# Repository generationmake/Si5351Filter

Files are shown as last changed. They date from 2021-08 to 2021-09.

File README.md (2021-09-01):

# Si5351Filter
Filter board for Si 5351 for WSPR or similar purposes.

Should fit perfectly to the [Adafruit Si5351A Clock Generator Breakout Board](https://www.adafruit.com/product/2045)

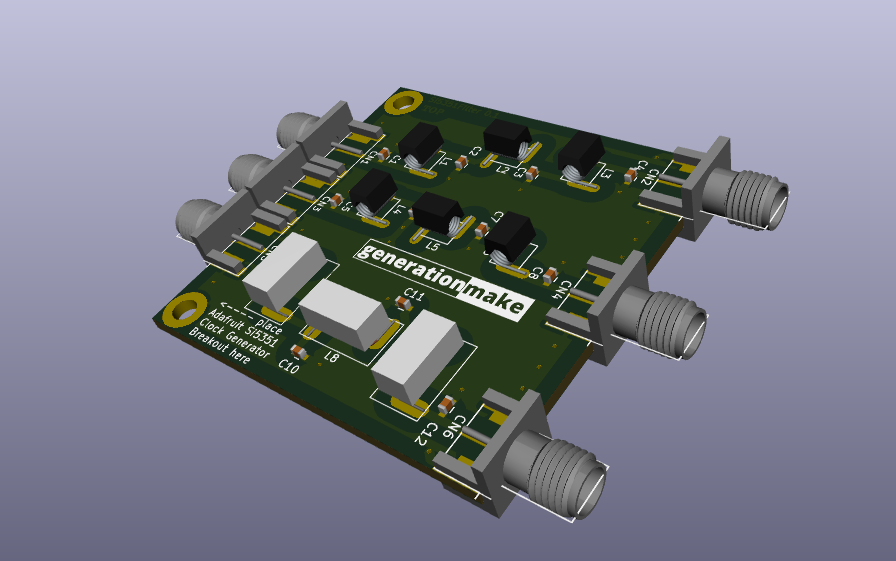
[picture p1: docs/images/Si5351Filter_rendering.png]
Si5351Filter rendering


## PCB

### Top

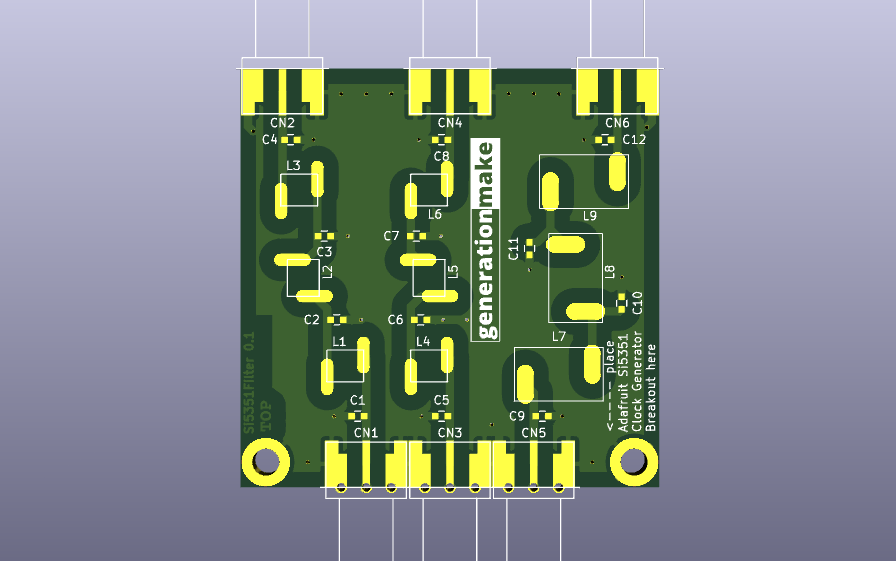
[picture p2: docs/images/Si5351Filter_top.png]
Si5351Filter PCB top


### Bottom

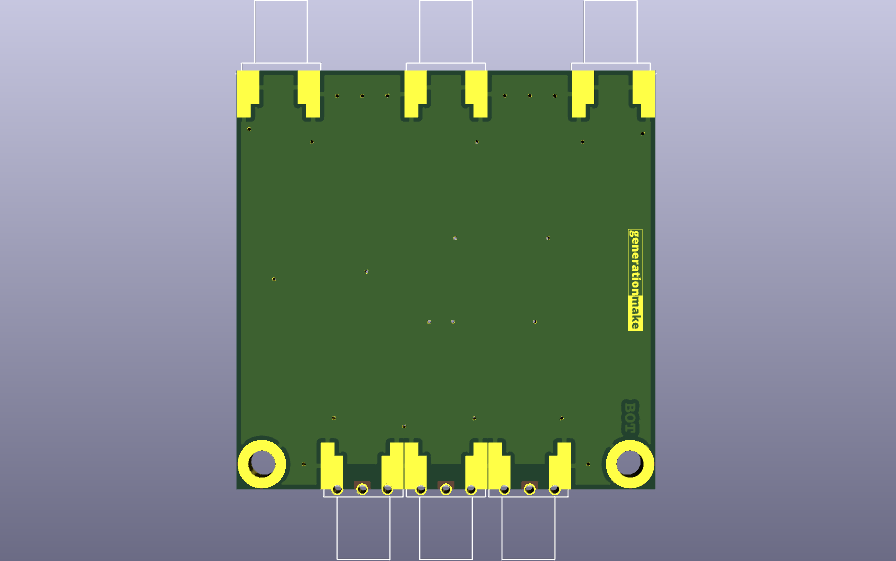
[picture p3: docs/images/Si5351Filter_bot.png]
Si5351Filter PCB bot


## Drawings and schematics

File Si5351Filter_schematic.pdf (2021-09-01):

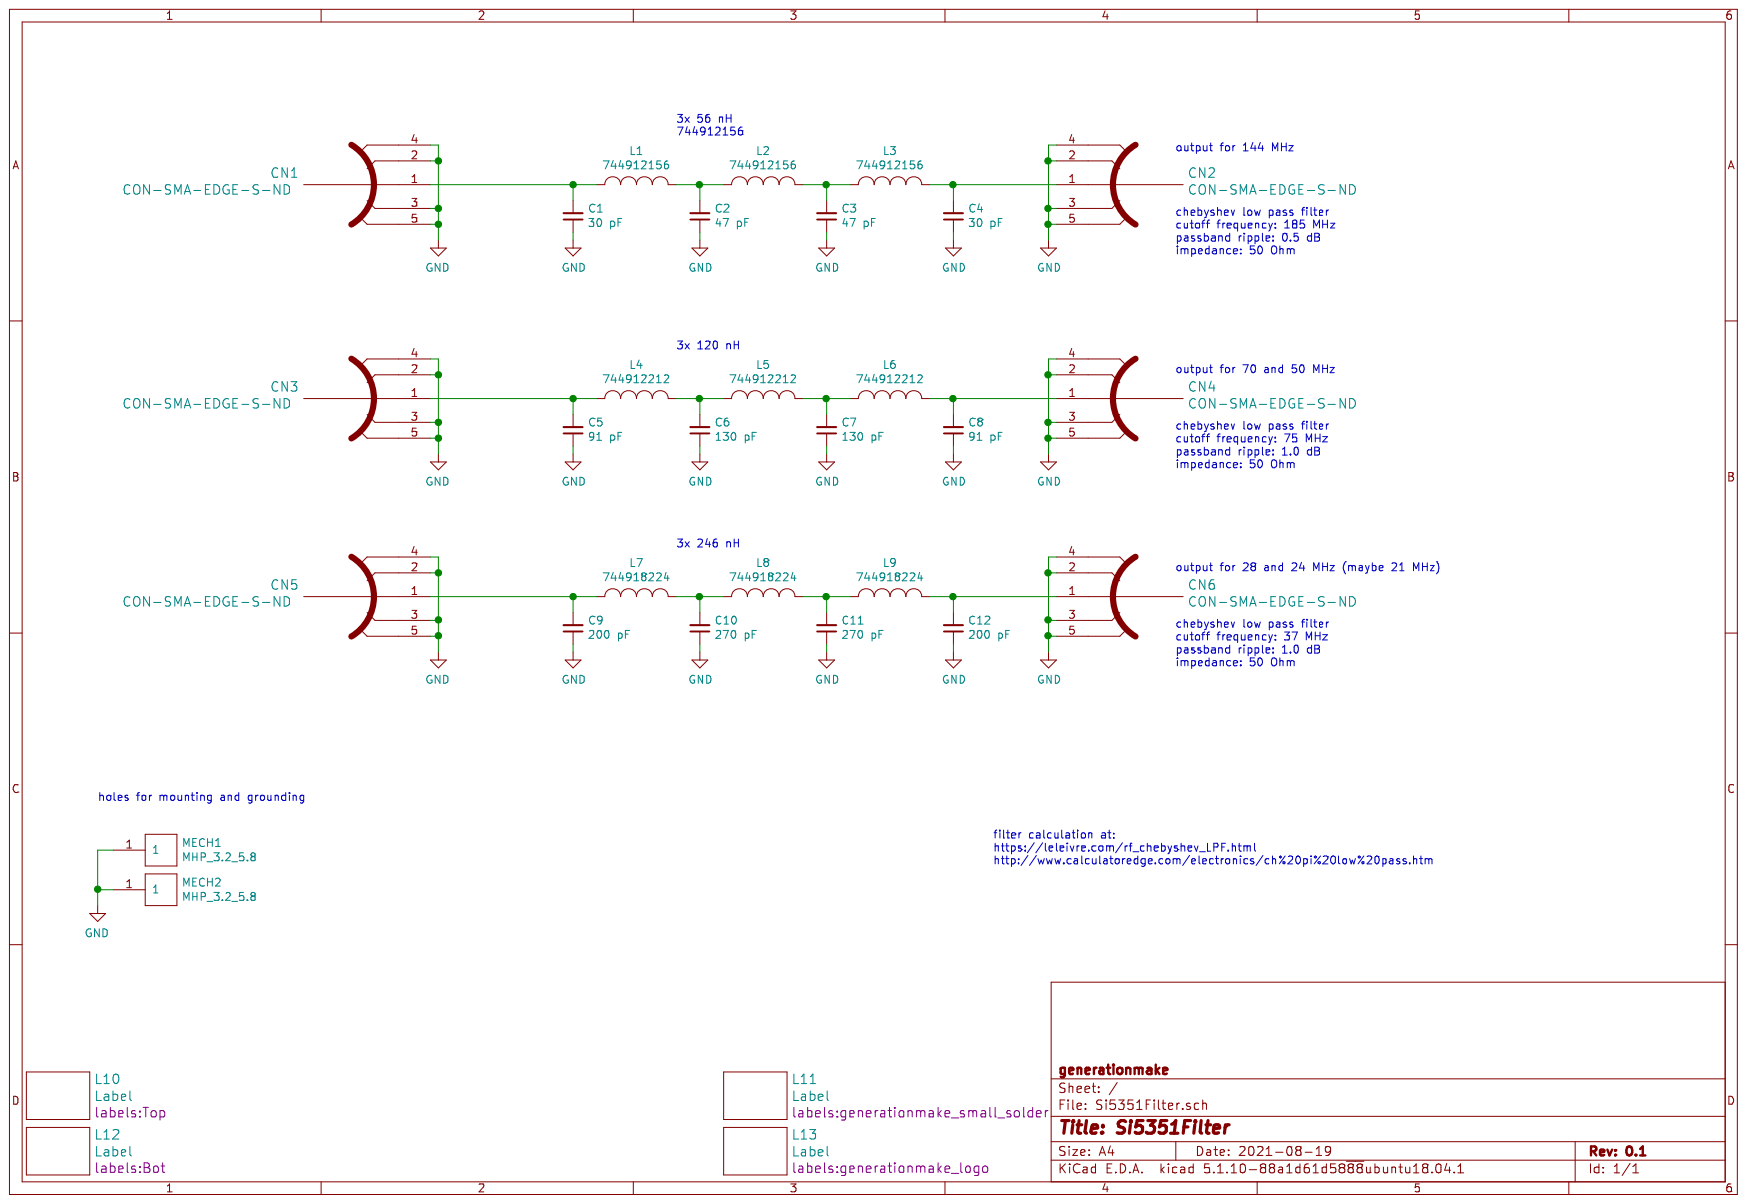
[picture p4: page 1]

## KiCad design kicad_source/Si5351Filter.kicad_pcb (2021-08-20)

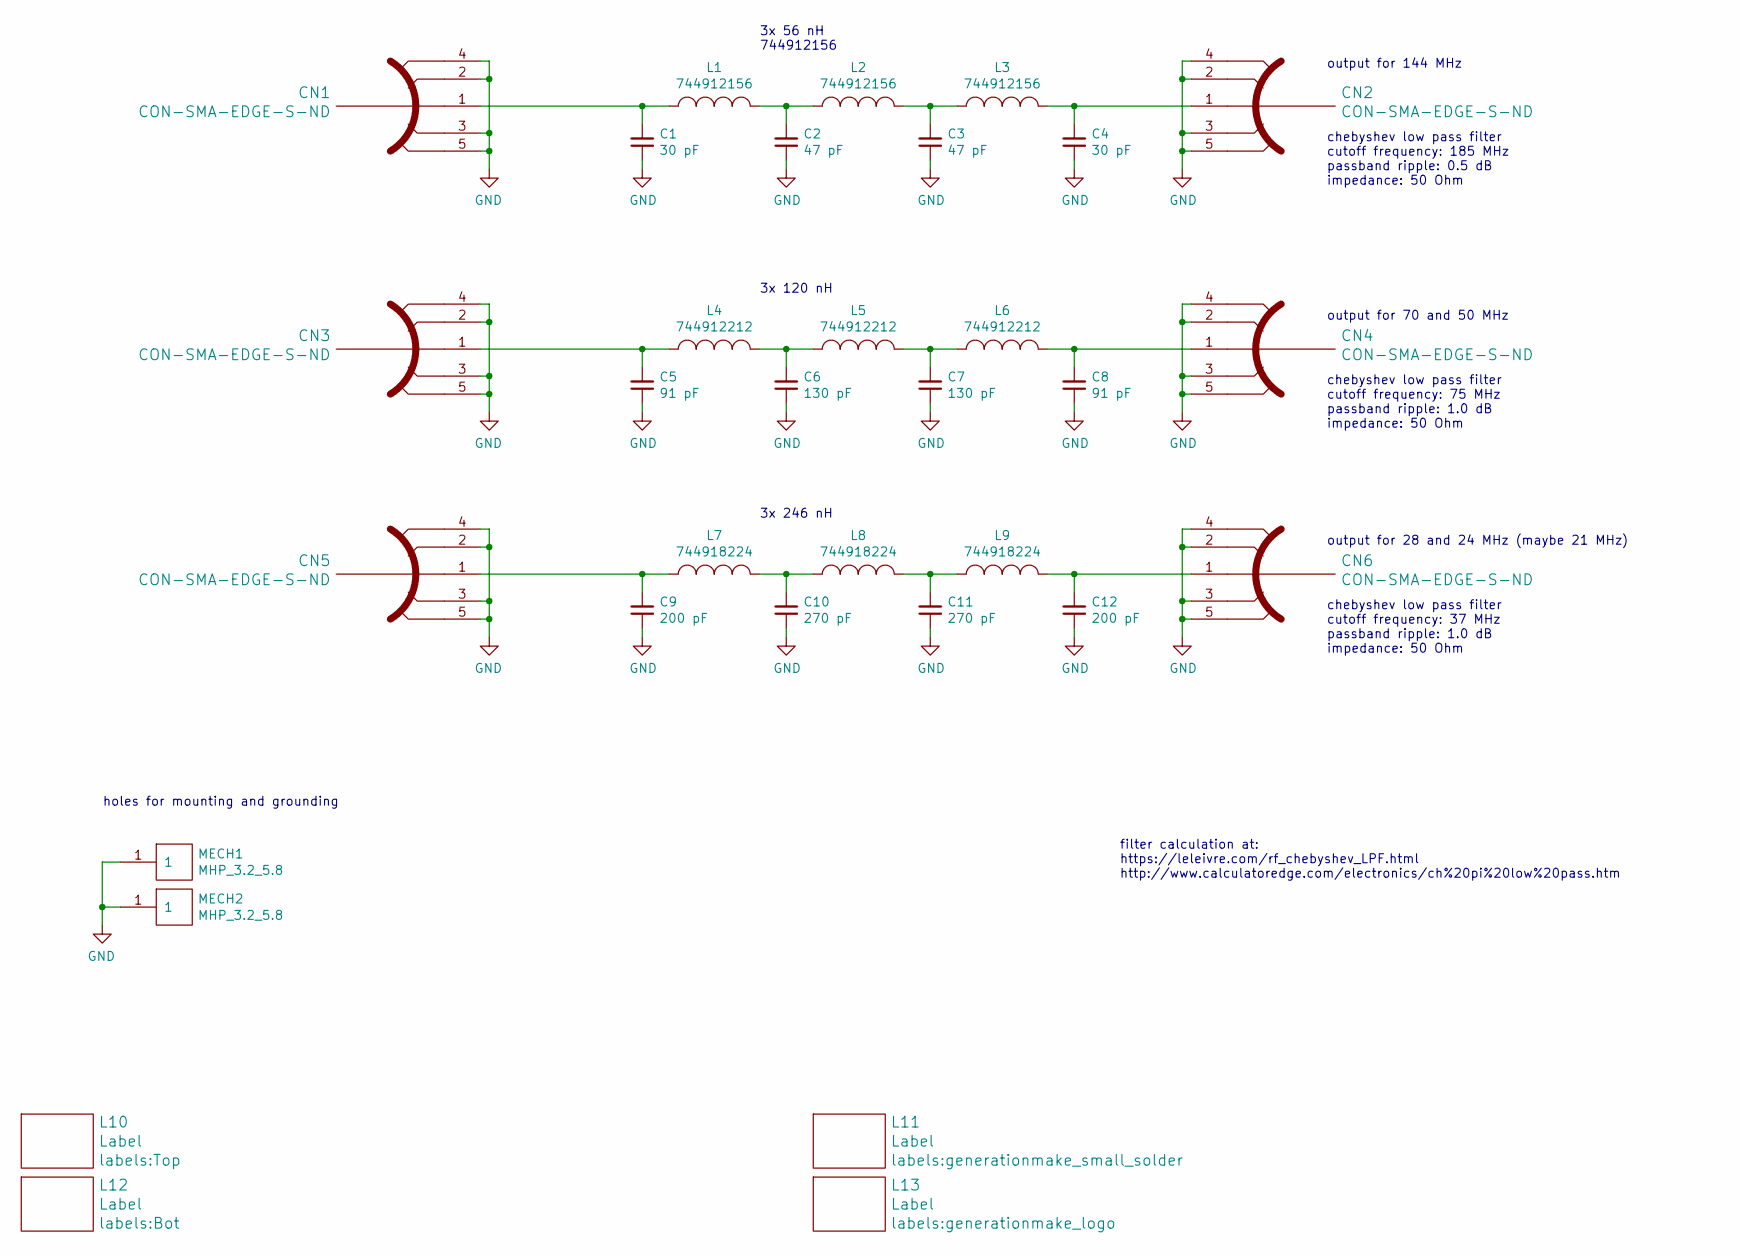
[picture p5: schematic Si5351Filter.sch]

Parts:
C1, C4: 30 pF; C_0603
C2, C3: 47 pF; C_0603
C5, C8: 91 pF; C_0603
C6, C7: 130 pF; C_0603
C9, C12: 200 pF; C_0603
C10, C11: 270 pF; C_0603
CN1, CN2, CN3, CN4, CN5, CN6: CON-SMA-EDGE-S-ND; WR-SMA-PCB_dual
L1, L2, L3: 744912156; WE-CAIR_4248
L4, L5, L6: 744912212; WE-CAIR_4248
L7, L8, L9: 744918224; WE-CAIR_5910
L10: Label; Top
L11: Label; generationmake_small_solder
L12: Label; Bot
L13: Label; generationmake_logo
MECH1, MECH2: MHP_3.2_5.8

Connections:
GND: C1.1, C2.1, C3.1, C4.1, C5.1, C6.1, C7.1, C8.1, C9.1, C10.1, C11.1, C12.1, CN1.2, CN1.3, CN1.4, CN1.5, CN2.2, CN2.3, CN2.4, CN2.5, CN3.2, CN3.3, CN3.4, CN3.5, CN4.2, CN4.3, CN4.4, CN4.5, CN5.2, CN5.3, CN5.4, CN5.5, CN6.2, CN6.3, CN6.4, CN6.5, MECH1.1, MECH2.1
unnamed: C1.2, CN1.1, L1.1
unnamed: C2.2, L1.2, L2.1
unnamed: C3.2, L2.2, L3.1
unnamed: C4.2, CN2.1, L3.2
unnamed: C5.2, CN3.1, L4.1
unnamed: C6.2, L4.2, L5.1
unnamed: C7.2, L5.2, L6.1
unnamed: C8.2, CN4.1, L6.2
unnamed: C9.2, CN5.1, L7.1
unnamed: C10.2, L7.2, L8.1
unnamed: C11.2, L8.2, L9.1
unnamed: C12.2, CN6.1, L9.2

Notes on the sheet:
output for 144 MHz
output for 70 and 50 MHz
3x 120 nH
3x 56 nH 744912156
chebyshev low pass filter cutoff frequency: 185 MHz passband ripple: 0.5 dB impedance: 50 Ohm
chebyshev low pass filter cutoff frequency: 75 MHz passband ripple: 1.0 dB impedance: 50 Ohm
filter calculation at: https://leleivre.com/rf_chebyshev_LPF.html http://www.calculatoredge.com/electronics/ch%20pi%20low%20pass.htm
output for 28 and 24 MHz (maybe 21 MHz)
3x 246 nH
chebyshev low pass filter cutoff frequency: 37 MHz passband ripple: 1.0 dB impedance: 50 Ohm
holes for mounting and grounding

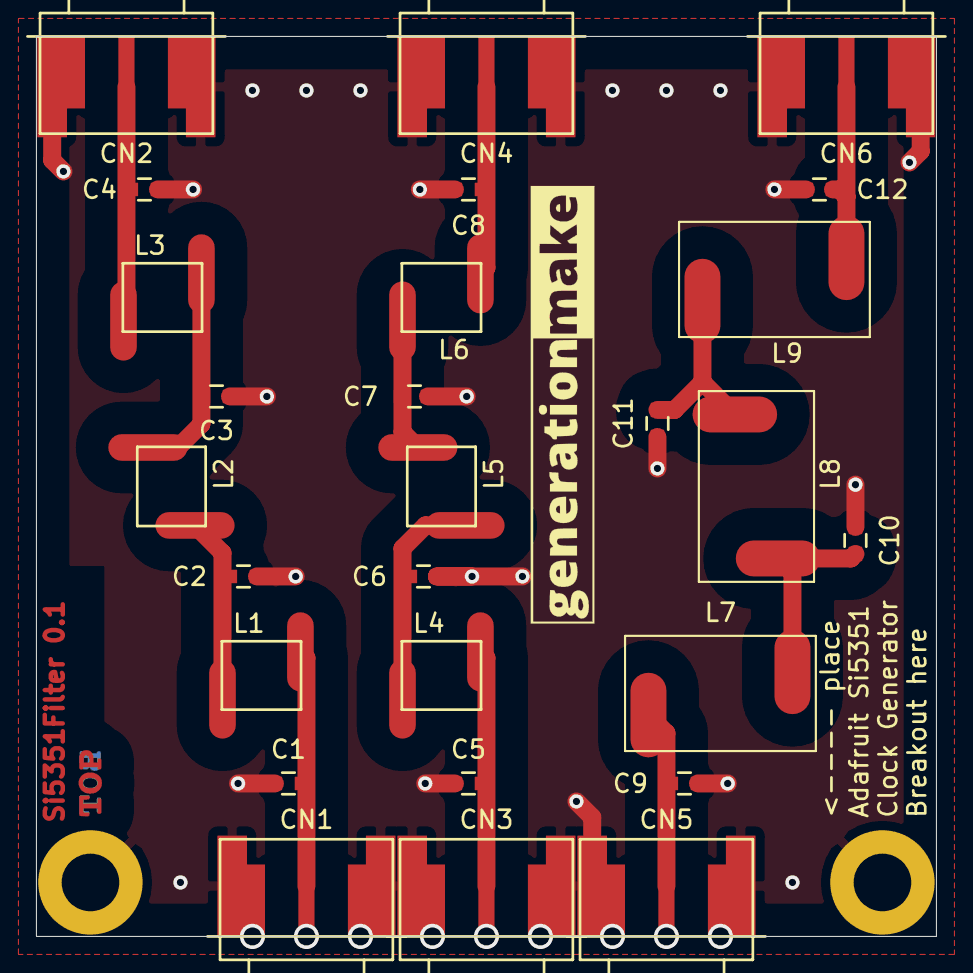
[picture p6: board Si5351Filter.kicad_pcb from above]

Board: 2 copper layers, 50.0 x 50.0 mm, 33 parts (1 on the bottom side), 13 nets.

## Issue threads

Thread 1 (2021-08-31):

add BNC and SMA connectors for case mount

generationmake, 2021-08-31:
add a footprint for a BNC and a SMA connector with the possibility of a sealed mounting in a case. WSPR transmitters are often used outside. So there should be the possibility to use a IP65 case.

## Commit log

2021-08-19 added design with schematic and layout
    [Si5351Filter.kicad_pcb, Si5351Filter.sch]
2021-08-19 added dual footprint for big and small SMA connectors
    [Si5351Filter.kicad_pcb, Si5351Filter.sch]
2021-08-19 added holes for mounting and grounding
    [Si5351Filter.kicad_pcb, Si5351Filter.sch]
2021-08-20 updated castellated holes
    [Si5351Filter.kicad_pcb]
2021-08-20 updated polygons
    [Si5351Filter.kicad_pcb]
2021-09-01 added pdf schematic
